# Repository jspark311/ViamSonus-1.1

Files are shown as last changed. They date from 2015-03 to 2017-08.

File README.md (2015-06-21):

     __     ___                 ____                        
     \ \   / (_) __ _ _ __ ___ / ___|  ___  _ __  _   _ ___ 
      \ \ / /| |/ _` | '_ ` _ \\___ \ / _ \| '_ \| | | / __|
       \ V / | | (_| | | | | | |___) | (_) | | | | |_| \__ \
        \_/  |_|\__,_|_| |_| |_|____/ \___/|_| |_|\__,_|___/

Viam Sonus *("Sound Route")* is an IoT audio multiplexer implemented on top of a Teensy3.1 running ManuvrOS.

----------------------
####What is in this repository:
**./3DModels**: Blender models of the physical pieces that comprise a finished unit.

**./doc**:  Documentation related to this project.
    
**./KiCAD**:  KiCAD project data for building a unit.

**./src**:  Original (unless otherwise specified) source code.

----------------------
####Building the device firmware 

I got sick of tracking the inconsistent behavior of the Arduino IDE, and so Viam Sonus was re-tooled to be buildable with a makefile against the Arduino libraries.

This project has ManuvrOS as a dependency. You will first need to add to this project's source tree:

    git clone https://github.com/Manuvr/ManuvrOS
    cd ManuvrOS*
    mv ManuvrOS StringBuilder DataStructures ..

You will also need the [Teensy3 enhanced i2c library](https://github.com/nox771/i2c_t3). Follow those installation proceedures to get better i2c support. Ultimately, this needs to be fixed in ManuvrOS.

One last step. You will need the [teensy_loader_cli program](https://github.com/PaulStoffregen/teensy_loader_cli) program to flash the controller with the new build. Build it, and place the binary in a place you deem logical, and then update the Makefile to reflect your choice.

The Makefile might need to be changed to reflect the location of your Arduino environment location.

----------------------
####Building the device firmware for a RasPi

This project relies on certain capabilities of the Teensy3.1, but a feature-restricted RasPi build is possible in-principle. If there enough interest, I will post instructions for it.

----------------------
Bitcoin accelerates feature requests and bug fixes. :-)

**16SeqCTSkx7tUj9kXKyzYuVMQ4ghs2HNK**

----------------------
####License
Original code is GPL v2. 

Code adapted from others' work inherrits their license terms, which were preserved in the commentary where it applies. 

----------------------
####Cred:
The ASCII art in this file was generated by [this most-excellent tool](http://patorjk.com/software/taag).

Some of the hardware drivers are adaptions from Adafruit or Teensyduino code. This is noted in each specific class so derived.

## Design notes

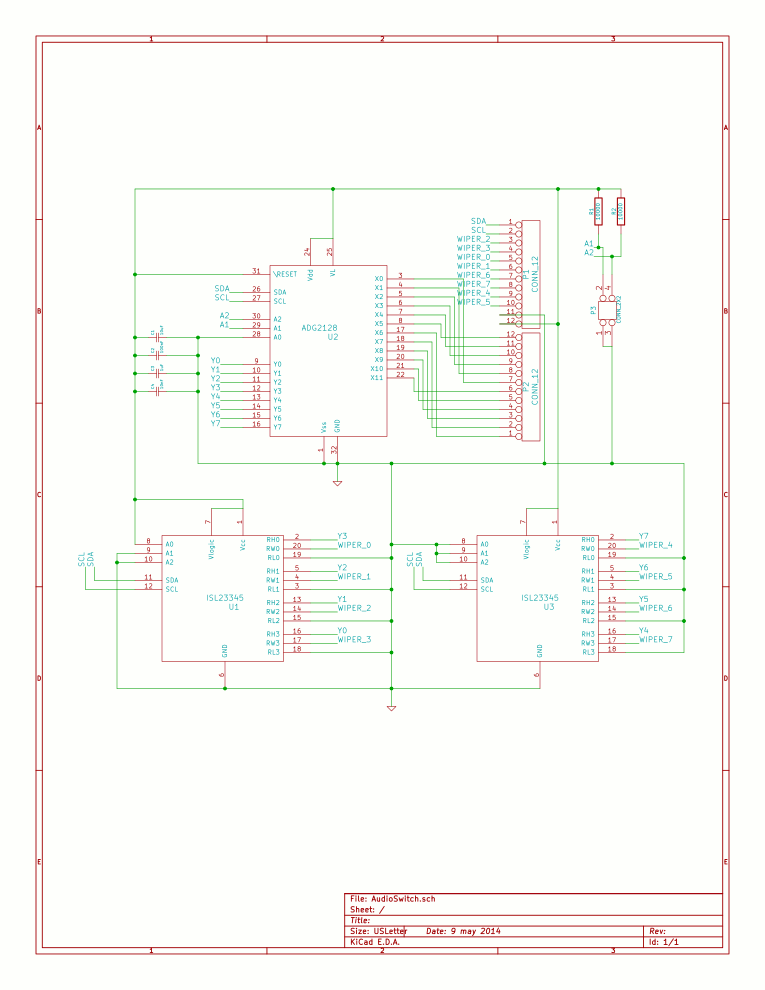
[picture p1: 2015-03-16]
KiCAD/AudioSwitch.gif

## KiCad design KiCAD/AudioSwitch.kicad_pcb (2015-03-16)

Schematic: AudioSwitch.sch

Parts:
C1: 10uF
C2: 100nF
C3: 1uF
C4: 10nF
P1, P2: CONN_12
P3: CONN_2X2
R1, R2: 10000
U1, U3: ISL23345
U2: ADG2128

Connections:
/A1: P3.2, R1.1, U2.29 (A1)
/A2: P3.4, R2.1, U2.30 (A2)
/SCL: P1.2, U1.12 (SCL), U2.27 (SCL), U3.12 (SCL)
/SDA: P1.1, U1.11 (SDA), U2.26 (SDA), U3.11 (SDA)
/WIPER_0: P1.5, U1.20 (RW0)
/WIPER_1: P1.6, U1.4 (RW1)
/WIPER_2: P1.3, U1.14 (RW2)
/WIPER_3: P1.4, U1.17 (RW3)
/WIPER_4: P1.9, U3.20 (RW0)
/WIPER_5: P1.10, U3.4 (RW1)
/WIPER_6: P1.7, U3.14 (RW2)
/WIPER_7: P1.8, U3.17 (RW3)
/Y0: U1.16 (RH3), U2.9 (Y0)
/Y1: U1.13 (RH2), U2.10 (Y1)
/Y2: U1.5 (RH1), U2.11 (Y2)
/Y3: U1.2 (RH0), U2.12 (Y3)
/Y4: U2.13 (Y4), U3.16 (RH3)
/Y5: U2.14 (Y5), U3.13 (RH2)
/Y6: U2.15 (Y6), U3.5 (RH1)
/Y7: U2.16 (Y7), U3.2 (RH0)
GND: C1.2, C2.2, C3.2, C4.2, P1.11, P3.1, P3.3, U1.3 (RL1), U1.6 (GND), U1.9 (A1), U1.10 (A2), U1.15 (RL2), U1.18 (RL3), U1.19 (RL0), U2.1 (Vss), U2.28 (A0), U2.32 (GND), U2.33, U3.3 (RL1), U3.6 (GND), U3.8 (A0), U3.9 (A1), U3.10 (A2), U3.15 (RL2), U3.18 (RL3), U3.19 (RL0); also elsewhere on the board
unnamed: C1.1, C2.1, C3.1, C4.1, P1.12, R1.2, R2.2, U1.1 (Vcc), U1.7 (Vlogic), U1.8 (A0), U2.24 (Vdd), U2.25 (VL), U2.31 (\RESET), U3.1 (Vcc), U3.7 (Vlogic)
unnamed: P2.10, U2.6 (X3)
unnamed: P2.7, U2.3 (X0)
unnamed: P2.6, U2.22 (X11)
unnamed: P2.5, U2.21 (X10)
unnamed: P2.4, U2.20 (X9)
unnamed: P2.2, U2.18 (X7)
unnamed: P2.12, U2.8 (X5)
unnamed: P2.11, U2.7 (X4)
unnamed: P2.8, U2.4 (X1)
unnamed: P2.9, U2.5 (X2)
unnamed: P2.1, U2.17 (X6)
unnamed: P2.3, U2.19 (X8)

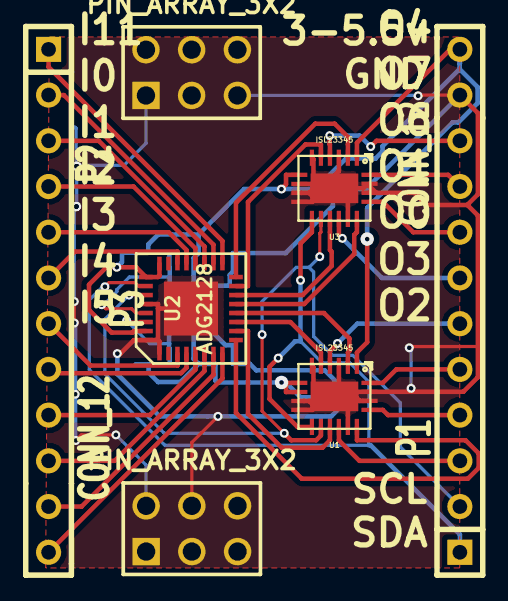
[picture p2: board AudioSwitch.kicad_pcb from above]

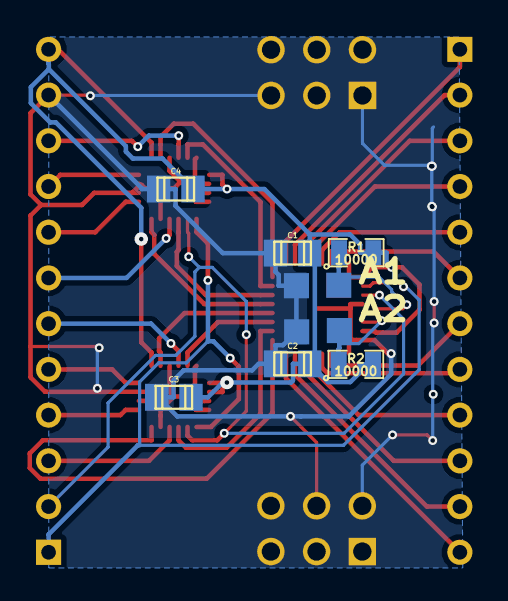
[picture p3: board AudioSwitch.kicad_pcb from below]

Board: 2 copper layers, 14 parts (6 on the bottom side), 34 nets.

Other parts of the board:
PIN_ARRAY_3X2, PIN_ARRAY_3X2#2: Val**; pin_array_3x2

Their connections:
GND: PIN_ARRAY_3X2.1, PIN_ARRAY_3X2.2, PIN_ARRAY_3X2.3, PIN_ARRAY_3X2.4, PIN_ARRAY_3X2.5, PIN_ARRAY_3X2.6, PIN_ARRAY_3X2#2.1, PIN_ARRAY_3X2#2.2, PIN_ARRAY_3X2#2.3, PIN_ARRAY_3X2#2.4, PIN_ARRAY_3X2#2.5, PIN_ARRAY_3X2#2.6; also elsewhere on the board

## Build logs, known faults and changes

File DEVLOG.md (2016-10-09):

# This is not a CHANGELOG
It is a verbose running commentary with no relationship to versioning.
File should be read top-to-bottom for chronological order.
The contents of this file will be periodically archived and purged to keep the log related to the "current events" of the code base.

_---J. Ian Lindsay 2016.08.27_

------

### 2016.09.03

After a long period of neglect, I feel the need to fix ViamSonus and bring it into
alignment with the last year of changes to Manuvr. Most of this is related to Makefiles
and build options. But some of Manuvr's drivers were never updated.
Still unable to build. Not done modernizing...

Hey! I finished, and it's still today (23:33).
Committing...

_---J. Ian Lindsay_

------

### 2016.09.04
Still at it. Cleaning up loose-ends and knocking down TODO's in Manuvr.
Neopixels behave abnormally. Fixed a serious bug in Teensy3 platform, as well
  as a few in the Kernel.

      text    data     bss     dec     hex
     84040    3608    5128   92776   16a68   Current build size with DEBUG and no RTOS.
     84776    3608    5128   93512   16d48   Extensions to NeoPixel.
     84768    3608    5128   93504   16d40   Small fixes. About to optimize...
     84808    3608    5128   93544   16d68   Removal of pointless heap usage.
     98836    3648    5180  107664   1a490   New baseline after platform upgrades.
     98820    3648    5180  107648   1a480   Following removal of runtime mes_def length check.

Massive binge in manuvr this weekend. CBOR support was added.
     98868    3648    5180  107696   1a4b0   CBOR and R/W storage support.
    100668    3648    5180  109496   1abb8   Adding automatic config loading and config dump.

Calling it a weekend....
_---J. Ian Lindsay_

------

### 2016.09.10
    make DEBUG=1
    100668    3648    5180  109496   1abb8   Prior baseline.
    101292    3648    5192  110132   1ae34   Following identity changes in Manuvr.
    101408    3648    5192  110248   1aea8   Following polymorphic platform conversion.
    101752    3648    5192  110592   1b000   Addition of extra module to be the glue.

Finally lost StaticHub. The last StaticHub.

_---J. Ian Lindsay_

------

### 2016.10.08
Security via mbedTLS

    make DEBUG=1
    78192    3584    3932   85708   14ecc  Prior to semantic_args excision.
    78016    3584    3932   85532   14e1c  After semantic_args excision.

    169620    3664    8732  182016   2c700 DEBUG=1 SECURE=1 THREADS=1
    167740    3656    8500  179896   2beb8 DEBUG=1 SECURE=1
    101616    3632    5116  110364   1af1c DEBUG=1
    91760     3624    5084  100468   18874 <No qualifiers>

_---J. Ian Lindsay_

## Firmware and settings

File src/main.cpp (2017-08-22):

/*
File:   main.cpp
Author: J. Ian Lindsay
Date:   2014.05.19

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
     __     ___                 ____
     \ \   / (_) __ _ _ __ ___ / ___|  ___  _ __  _   _ ___
      \ \ / /| |/ _` | '_ ` _ \\___ \ / _ \| '_ \| | | / __|
       \ V / | | (_| | | | | | |___) | (_) | | | | |_| \__ \
        \_/  |_|\__,_|_| |_| |_|____/ \___/|_| |_|\__,_|___/

Supported build targets: Teensy3 and Raspi.
*/

#include <Audio/Audio.h>
#include "Encoder/Encoder.h"
//#include <Audio/utility/dspinst.h>
#include "arm_math.h"

#include <DataStructures/StringBuilder.h>
#include <Platform/Platform.h>

#include <Drivers/ManuvrableNeoPixel/ManuvrableNeoPixel.h>
#include <Drivers/AudioRouter/AudioRouter.h>
#include <Drivers/LightSensor/LightSensor.h>
#include <Drivers/ADCScanner/ADCScanner.h>
#include <Transports/ManuvrSerial/ManuvrSerial.h>
#include <XenoSession/Console/ManuvrConsole.h>

#define HOST_BAUD_RATE  115200
#define NEOPIXEL_PIN  11



// These are only here until they are migrated to each receiver that deals with them.
const MessageTypeDef message_defs_viam_sonus[] = {
  {  VIAM_SONUS_MSG_ENCODER_UP       , 0x0000,  "ENCODER_UP",    ManuvrMsg::MSG_ARGS_NONE },   // The encoder on the front panel was incremented.
  {  VIAM_SONUS_MSG_ENCODER_DOWN     , 0x0000,  "ENCODER_DOWN",  ManuvrMsg::MSG_ARGS_NONE },   // The encoder on the front panel was decremented.

  /* ViamSonus has neopixels and a light-level sensor. */
  {  MANUVR_MSG_NEOPIXEL_REFRESH     , 0x0000,  "NEOPIXEL_REFRESH",  ManuvrMsg::MSG_ARGS_NONE }, // Cause any neopixel classes to refresh their strands.
  {  MANUVR_MSG_DIRTY_FRAME_BUF      , 0x0000,  "DIRTY_FRAME_BUF",   ManuvrMsg::MSG_ARGS_NONE }, // Something changed the framebuffer and we need to redraw.

  /* ViamSonus has hardware buttons... */
  {  MANUVR_MSG_USER_BUTTON_PRESS    , MSG_FLAG_EXPORTABLE,  "USER_BUTTON_PRESS",    ManuvrMsg::MSG_ARGS_NONE },   // The user pushed a button with the given integer code.
  {  MANUVR_MSG_USER_BUTTON_RELEASE  , MSG_FLAG_EXPORTABLE,  "USER_BUTTON_RELEASE",  ManuvrMsg::MSG_ARGS_NONE },   // The user released a button with the given integer code.
};


const I2CAdapterOptions i2c_opts(
  1,   // Device number
  30, // sda
  29  // scl
);


StringBuilder local_log;

Kernel*             kernel        = NULL;
Encoder*            encoder_stack = NULL;
AudioRouter*        audio_router  = NULL;
ManuvrableNeoPixel* strip         = NULL;
LightSensor*        light_sensor  = NULL;
ADCScanner*         adc_scanner   = NULL;


/****************************************************************************************************
* Audio test code.                                                                                  *
****************************************************************************************************/
//AudioSynthToneSweep myEffect;
//AudioOutputAnalog   audioOutput;
//
//// The tone sweep goes to left and right channels
//AudioConnection c1(myEffect, 0, audioOutput, 0);
//AudioConnection c2(myEffect, 0, audioOutput, 1);
//
//float t_ampx = 0.8;
//int t_lox = 10;
//int t_hix = 22000;
//// Length of time for the sweep in seconds
//float t_timex = 10;




/****************************************************************************************************
* Entry-point for teensy3...                                                                        *
****************************************************************************************************/

int last_touch_read[12] = {0, 0, 0, 0, 0, 0, 0, 0, 0, 0, 0, 0};
long last_encoder_read = 0;


uint8_t analog_write_val = 0;
int8_t direction = 1;   // Zero for hold, 1 for brighten, -1 for darken.

void logo_fade() {
  if (direction < 0) analog_write_val--;
  else if (direction > 0) analog_write_val++;
  else return;

  if (0 == analog_write_val) {
    direction = direction * -1;
  }
  else if (200 == analog_write_val) {
    direction = direction * -1;
  }
  analogWrite(4, analog_write_val);
}


void scan_buttons() {
  int current_touch_read[12] = {
    touchRead(0),
    touchRead(1),
    touchRead(15),
    touchRead(16),
    touchRead(17),
    touchRead(18),
    touchRead(19),
    touchRead(22),
    touchRead(23),
    touchRead(25),
    touchRead(32),
    touchRead(33)
  };

  long current_encoder_read = encoder_stack->read();
  if (current_encoder_read) {
    last_encoder_read += current_encoder_read;
    ManuvrMsg* event = Kernel::returnEvent((current_encoder_read > 0) ? VIAM_SONUS_MSG_ENCODER_UP : VIAM_SONUS_MSG_ENCODER_DOWN);
    Kernel::staticRaiseEvent(event);

    local_log.concatf("Encoder changed. %lu\n", current_encoder_read);
    Kernel::log(&local_log);
  }

  for (int i = 0; i < 12; i++) {
    // Real cheesy. Going to look for a doubling until I write calibration code.
    if (last_touch_read[i] == 0) {
      // First run. Do nothing.
    }
    else if (last_touch_read[i]*2 < current_touch_read[i]) {
      // BIG rise
      ManuvrMsg* event = Kernel::returnEvent(MANUVR_MSG_USER_BUTTON_PRESS);
      event->addArg((uint8_t) i);
      Kernel::staticRaiseEvent(event);

      local_log.concatf("Button %d pressed.\n", i);
      Kernel::log(&local_log);
    }
    else if (current_touch_read[i]*2 < last_touch_read[i]) {
      // BIG fall
      ManuvrMsg* event = Kernel::returnEvent(MANUVR_MSG_USER_BUTTON_RELEASE);
      event->addArg((uint8_t) i);
      Kernel::staticRaiseEvent(event);

      local_log.concatf("Button %d released.\n", i);
      Kernel::log(&local_log);
    }
    else {
      // Steady-state. Nominal case.
    }
    last_touch_read[i] = current_touch_read[i];
  }
}


void setup() {
  // One of the first things we need to do is populate the EventManager with all of the
  // message codes that come with this firmware.
  int mes_count = sizeof(message_defs_viam_sonus) / sizeof(MessageTypeDef);
  ManuvrMsg::registerMessages(message_defs_viam_sonus, mes_count);

  platform.platformPreInit();
  kernel = platform.kernel();

  //analogReadRes(BEST_ADC_PRECISION);  // All ADC channels shall be 10-bit.
  analogReadAveraging(32);            // And maximally-smoothed by the hardware (32).
  analogWriteResolution(12);   // Setup the DAC.

  gpioDefine(13, GPIOMode::OUTPUT);
  gpioDefine(11, GPIOMode::OUTPUT);
  gpioDefine(4,  GPIOMode::OUTPUT);
  gpioDefine(2,  GPIOMode::INPUT_PULLUP);
  gpioDefine(3,  GPIOMode::INPUT_PULLUP);
  gpioDefine(14, GPIOMode::INPUT);
}


void loop() {
  //AudioMemory(2);

  // Setup the first i2c adapter and Subscribe it to Kernel.
  I2CAdapter i2c(&i2c_opts);

  kernel->subscribe((EventReceiver*) &i2c);

  const uint8_t SWITCH_ADDR = 0x76;
  const uint8_t POT_0_ADDR  = 0x50;
  const uint8_t POT_1_ADDR  = 0x51;
  audio_router = new AudioRouter((I2CAdapter*) &i2c, SWITCH_ADDR, POT_0_ADDR, POT_1_ADDR);

  encoder_stack = new Encoder(2, 3);
  strip = new ManuvrableNeoPixel(80, NEOPIXEL_PIN, NEO_GRB + NEO_KHZ800);
  light_sensor = new LightSensor(A0);
  adc_scanner = new ADCScanner();
  adc_scanner->addADCPin(A10);
  adc_scanner->addADCPin(A11);
  adc_scanner->addADCPin(A12);
  adc_scanner->addADCPin(A13);
  adc_scanner->addADCPin(A15);
  adc_scanner->addADCPin(A16);
  adc_scanner->addADCPin(A17);
  adc_scanner->addADCPin(A6);
  adc_scanner->addADCPin(A7);
  adc_scanner->addADCPin(A20);

  kernel->subscribe((EventReceiver*) adc_scanner);
  kernel->subscribe((EventReceiver*) audio_router);
  kernel->subscribe((EventReceiver*) strip);
  kernel->subscribe((EventReceiver*) light_sensor);

  platform.bootstrap();

  kernel->createSchedule(40, -1, false, logo_fade)->enableSchedule(true);
  kernel->createSchedule(100,  -1, false, scan_buttons)->enableSchedule(true);

  ManuvrSerial  _console_xport("U", HOST_BAUD_RATE);  // Indicate USB.
  kernel->subscribe((EventReceiver*) &_console_xport);
  ManuvrConsole _console((BufferPipe*) &_console_xport);
  kernel->subscribe((EventReceiver*) &_console);

  while (1) {
    kernel->procIdleFlags();
  }
}


#if defined(__MANUVR_LINUX)
  // For linux builds, we provide a shunt into the loop function.
  int main(int argc, char *argv[]) {
    setup();
    loop();
  }
#endif

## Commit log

2015-03-16 Initial release of ViamSonus firmware.
    [AudioSwitch.dsn, AudioSwitch.kicad_pcb, AudioSwitch.sch]
2015-03-17 Realized there was Arduino broken-ness left over. Still isn't completely fixed.
    [ViamSonus.ino]
2015-03-17 Adding warning about i2c library.
2015-03-21 Broken i2c bus, but I'm pretty sure the problem is in ManuvrOS.
    [ViamSonus.ino]
2015-06-19 Fixing bug that caused a nasty hang on boot.
    [ViamSonus.ino]
2015-06-21 Separating build process from Arduino IDE. Adding Makefile. Putting source files in locations with less brain-damage.
    [ViamSonus.cpp]
2015-06-21 Updating README to reflect the abandonment of the Arduino build system.
2015-06-21 Crash fixed. Cause was failure to proc events.
    [ViamSonus.cpp]
2015-10-08 Removing drivers from ViamSonus before ripping it up.
2016-09-04 More build fixes. About to move to neglected Manuvr drivers.
    [ViamSonus.cpp]
